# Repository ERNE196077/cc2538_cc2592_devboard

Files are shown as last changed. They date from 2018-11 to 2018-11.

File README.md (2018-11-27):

# cc2538_cc2592_devboard
This board is small enough to fit in a breadboard and let one space for pin connectivity, some features are:
* APA102 2020 onboard.
* FTDI FT232 UART-USB transceiver onboard 
* SN74AHCT125 onboard for 5v TTL (PA5 & PA6)
* RP SMA Female connector for high gain antenna
* Power consumption with LED working and SPI trasmitting each 100 ms = 0.05 A
* Dedicated Flash (PA2) and Reset buttons. 

## Flashing instructions for OpenThread
I'm using the cc2538-bsl.py script from JelmerT to flash the board. All the recognitions goes to him: 
[cc2538-bsl](https://github.com/JelmerT/cc2538-bsl)

Set the bootloader in the board: Press Reset button while holding the Flash button.
Compile the cc2538 example as seen in the [OpenThread.io](https://openthread.io/guides/build) page.

*NOTE* Make sure to modify the dedicated pins in the file /examples/platforms/cc2538/startup-gcc.c to match the above ones.

Convert to binary the resulting image
```
arm-none-eabi-objcopy -O binary output/cc2538/bin/ot-cli-ftd output/cc2538/bin/ot-cli-ftd.bin
```
Flash the image
```
sudo python ./cc2538-bsl/cc2538-bsl.py -p /dev/ttyUSB0 -b 115200 -e -w -v -V  output/cc2538/bin/ot-cli-ftd.bin
```

## KICAD dependencies 
Make sure to update your KICAD and update the libraries. Then you will need to link and match the footprints and schematic components.
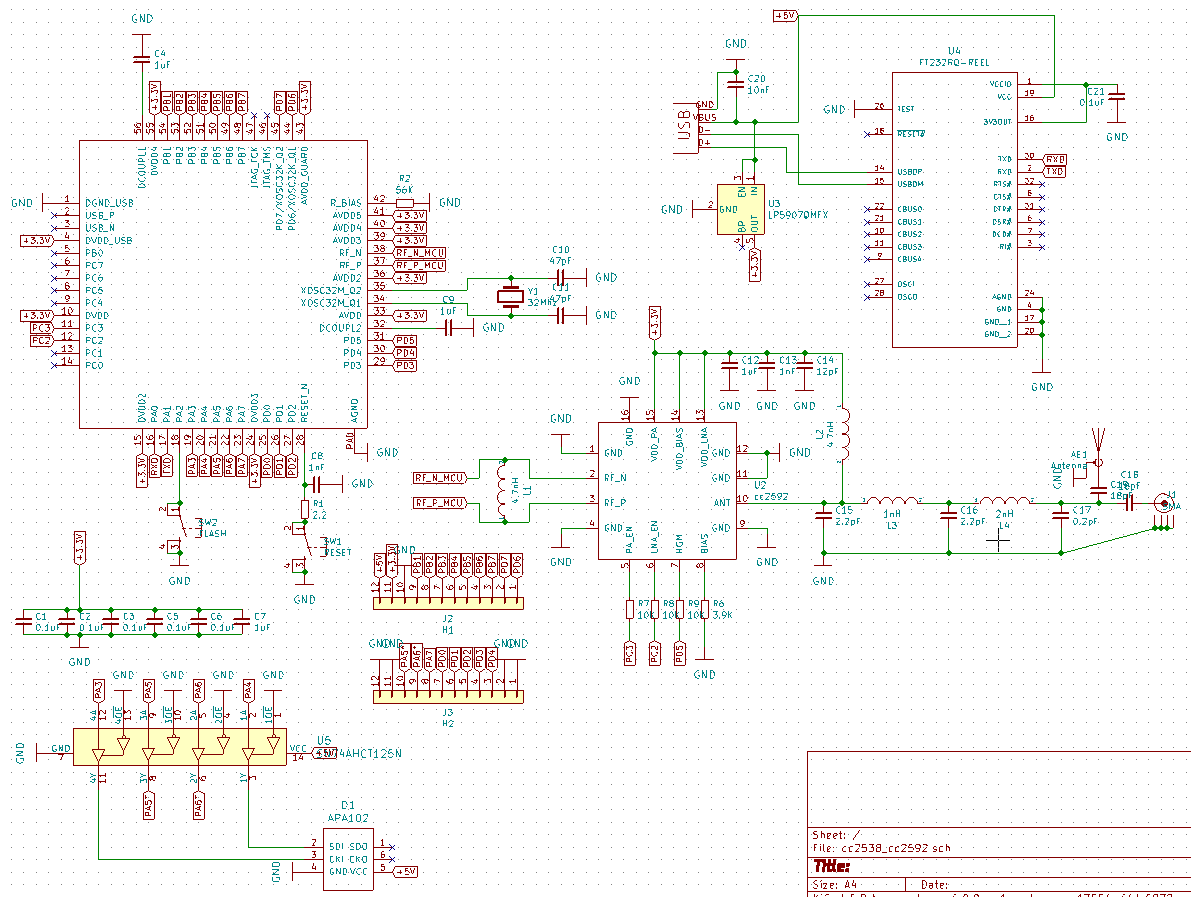
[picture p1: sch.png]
Schematic

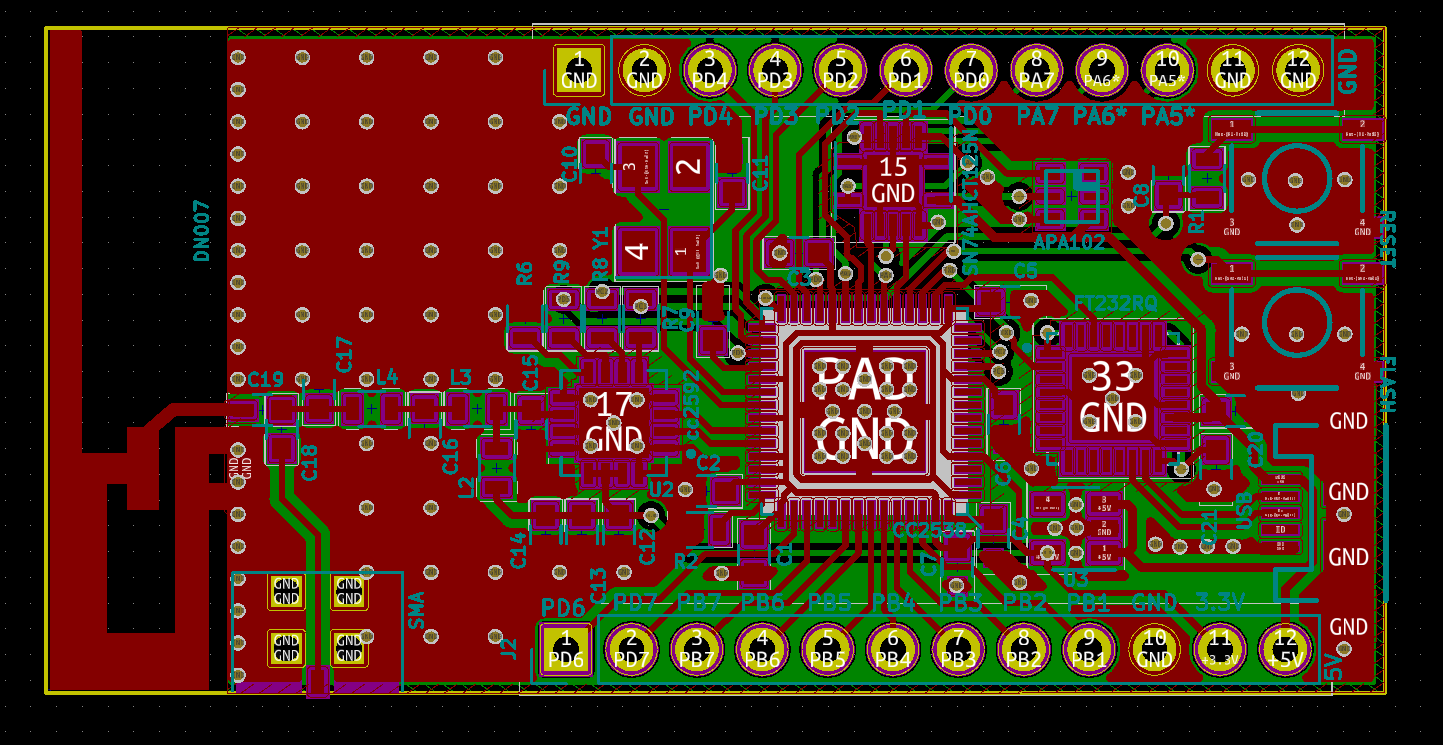
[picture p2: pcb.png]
PCB layout

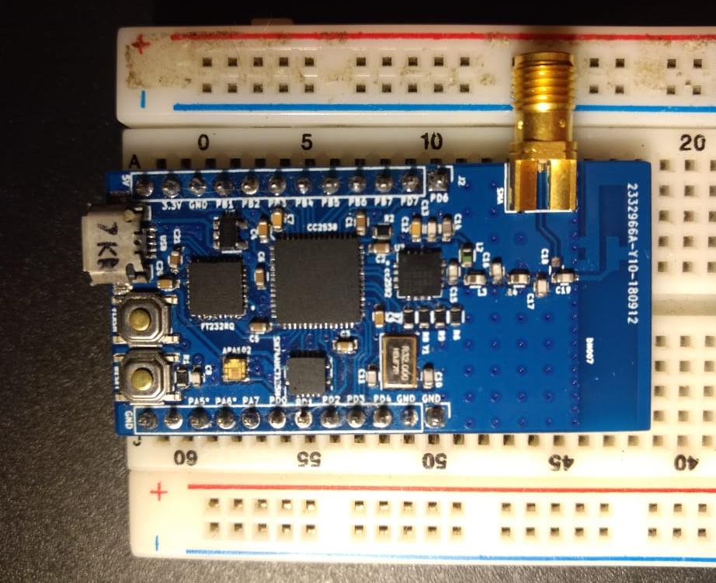
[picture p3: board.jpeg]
Board


## Libraries

Most of the work done with this board has been based in the OpenThread project, but custom libraries are available to fit the capabilities of this board:
[OpenThread](https://github.com/openthread/openthread)
[cc2538_cc2592_libs](https://github.com/ERNE196077/cc2538_cc2592_libs)

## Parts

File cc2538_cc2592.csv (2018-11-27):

Title
Revision
Date
Generated | Sun 10 Jun 2018 07:34:57 PM CDT
Company
Comment 1
Comment 2
Comment 3
Comment 4
Total Parts | 44
Total Unique Parts | 29
Ref | Qty | Value | Footprint | Datasheet | Field4 | Field5 | Field6 | Field7 | Field8
AE1 | 1 | Antenna | Antennas:Texas_SWRA117D_2.4GHz_Right
C1 C2 C3 C5 C6 C21 | 6 | 0.1uF | Capacitors_SMD:C_0603
C4 C7 C9 C12 | 4 | 1uF | Capacitors_SMD:C_0603
C8 C13 | 2 | 1nF | Capacitors_SMD:C_0603
C10 C11 | 2 | 47pF | Capacitors_SMD:C_0603
C14 | 1 | 12pF | Capacitors_SMD:C_0603
C15 C16 | 2 | 2.2pF | Capacitors_SMD:C_0603
C17 | 1 | 0.2pF | Capacitors_SMD:C_0603
C18 C19 | 2 | 18pF | Capacitors_SMD:C_0603
C20 | 1 | 10nF | Capacitors_SMD:C_0603
D1 | 1 | APA102 | gsg-modules:APA102-2020
J1 | 1 | A-1JB | A-1JB:AMPHENOL_A-1JB | Amphenol RF | 0.50 USD | A-1JB | Good | None | Connector | RF | AMC | PCB Jack | Surface Mnt | 50 Ohm | Solder
J2 | 1 | H1 | Pin_Headers:Pin_Header_Straight_1x18_Pitch2.54mm
J3 | 1 | H2 | Pin_Headers:Pin_Header_Straight_1x18_Pitch2.54mm
L1 L2 | 2 | 4.7nH | Inductors_SMD:L_0603
L3 | 1 | 1nH | Inductors_SMD:L_0603
L4 | 1 | 2nH o 1.8nH | Inductors_SMD:L_0603
R1 | 1 | 2.2 | Resistors_SMD:R_0603
R2 | 1 | 56K | Resistors_SMD:R_0603
R6 | 1 | 3.9K | Resistors_SMD:R_0603
R7 R8 R9 | 3 | 10K | Resistors_SMD:R_0603
SW1 | 1 | RESET | cc2538node:TACTILE_SWITCH_SMD
SW2 | 1 | FLASH | cc2538node:TACTILE_SWITCH_SMD
U1 | 1 | CC2538 | cc2538node:QFN56
U2 | 1 | cc2592 | QFN65P400X400X100-17N:QFN65P400X400X100-17N
U3 | 1 | LP5907QMFX | TO_SOT_Packages_SMD:SOT-23-5 | http://ww1.microchip.com/downloads/en/devicedoc/mic5219.pdf
U4 | 1 | FT232RQ-REEL | FT232RQ-REEL:QFN50P500X500X100-33N | Unavailable | None | FT232RQ | USB-to-UART 1-CH 256Byte FIFO 5V 32-Pin QFN EP | FTDI | 3.77 USD
USB1 | 1 | USBSMD | cc2538node:USB-MICROB
Y1 | 1 | 32Mhz | Crystals:Crystal_SMD_5032-4pin_5.0x3.2mm
BOM made with KICAD_BOM_WIZARD (https://github.com/HashDefineElectronics/KiCad_BOM_Wizard.git)
Generated Sun 10 Jun 2018 07:34:57 PM CDT

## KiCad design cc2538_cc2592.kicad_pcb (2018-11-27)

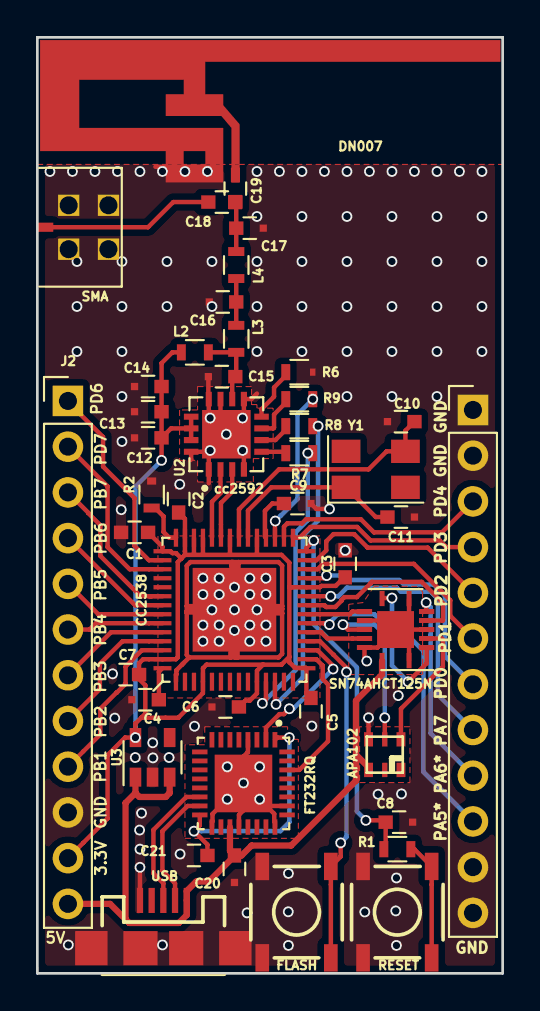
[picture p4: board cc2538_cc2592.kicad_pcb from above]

Board: 2 copper layers, 25.9 x 52.0 mm, 44 parts (0 on the bottom side), 53 nets.

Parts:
APA102: APA102; APA102-2020
C1, C2, C3, C5, C6, C21: 0.1uF; C_0603
C4, C7, C9, C12: 1uF; C_0603
C8, C13: 1nF; C_0603
C10, C11: 47pF; C_0603
C14: 12pF; C_0603
C15, C16: 2.2pF; C_0603
C17: 0.2pF; C_0603
C18, C19: 18pF; C_0603
C20: 10nF; C_0603
CC2538: CC2538; QFN56
DN007: Antenna; Texas_DN007
J2: H1; Pin_Header_Straight_1x12_Pitch2.54mm
J3: H2; Pin_Header_Straight_1x12_Pitch2.54mm
L2: 4.7nH; L_0603
L3: 1nH; L_0603
L4: 2nH; L_0603
R1: 2.2; R_0603
R2: 56K; R_0603
R6: 3.9K; R_0603
R7, R8, R9: 10K; R_0603
SMA: SMA; MOLEX_SMA_F_3460
SN74AHCT125N: SN74AHCT125N; Texas_S-PVQFN-N14
SW1: RESET; TACTILE_SWITCH_SMD
SW2: FLASH; TACTILE_SWITCH_SMD
U2: cc2592; QFN65P400X400X100-17N
U3: LP5907QMFX; SOT-23-5
U4: FT232RQ; QFN50P500X500X100-33N
USB1: USB; USB-MICROB
Y1: 32Mhz; Crystal_SMD_5032-4pin_5.0x3.2mm

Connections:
+3.3V: C1.1, C2.1, C3.1, C5.1, C6.1, C7.1, C12.1, C13.1, C14.1, CC2538.4, CC2538.10, CC2538.15, CC2538.24, CC2538.33, CC2538.36, CC2538.39, CC2538.40, CC2538.41, CC2538.43, CC2538.55, J2.11, L2.1, U2.13, U2.14, U2.15, U3.5
+5V: APA102.5, C20.2, J2.12, SN74AHCT125N.14, U3.1, U3.3, U4.19, USB1.VBUS
GND: APA102.4, C1.2, C2.2, C3.2, C4.1, C5.2, C6.2, C7.2, C8.1, C9.1, C10.1, C11.1, C12.2, C13.2, C14.2, C15.2, C16.2, C17.2, C20.1, C21.2, CC2538.1, CC2538.PAD, DN007.GND, J2.10, J3.1, J3.2, J3.11, J3.12, R2.1, R6.2, SMA.GND, SN74AHCT125N.1, SN74AHCT125N.4, SN74AHCT125N.7, SN74AHCT125N.10, SN74AHCT125N.13, SN74AHCT125N.15, SW1.3, SW1.4, SW2.3, SW2.4, U2.1, U2.4, U2.9, U2.11, U2.12, U2.16, U2.17, U3.2, U4.4, U4.17, U4.20, U4.24, U4.26, U4.33, USB1.GND
unnamed: C19.2, DN007.1
unnamed: C4.2, CC2538.56
unnamed: C8.2, CC2538.28, R1.1
unnamed: C9.2, CC2538.32
unnamed: C10.2, CC2538.35, Y1.3
unnamed: C11.2, CC2538.34, Y1.1
unnamed: C15.1, L2.2, L3.1, U2.10
unnamed: C16.1, L3.2, L4.1
unnamed: C17.1, C18.2, C19.1, L4.2
unnamed: C18.1, SMA.1
unnamed: C21.1, U4.1, U4.16
unnamed: APA102.2, SN74AHCT125N.3
unnamed: APA102.3, SN74AHCT125N.11
unnamed: R1.2, SW1.1, SW1.2
unnamed: CC2538.42, R2.2
unnamed: R6.1, U2.8
unnamed: R7.1, U2.5
unnamed: R8.1, U2.6
unnamed: R9.1, U2.7
unnamed: CC2538.18, SW2.1, SW2.2
unnamed: U4.14, USB1.D+
unnamed: U4.15, USB1.D-
PA3: CC2538.19, SN74AHCT125N.12
PA4: CC2538.20, SN74AHCT125N.2
PA5: CC2538.21, SN74AHCT125N.9
PA5*: J3.10, SN74AHCT125N.8
PA6: CC2538.22, SN74AHCT125N.5
PA6*: J3.9, SN74AHCT125N.6
PA7: CC2538.23, J3.8
PB1: CC2538.54, J2.9
PB2: CC2538.53, J2.8
PB3: CC2538.52, J2.7
PB4: CC2538.51, J2.6
PB5: CC2538.50, J2.5
PB6: CC2538.49, J2.4
PB7: CC2538.48, J2.3
PC2: CC2538.12, R8.2
PC3: CC2538.11, R7.2
PD0: CC2538.25, J3.7
PD1: CC2538.26, J3.6
PD2: CC2538.27, J3.5
PD3: CC2538.29, J3.4
PD4: CC2538.30, J3.3
PD5: CC2538.31, R9.2
PD6: CC2538.44, J2.1
PD7: CC2538.45, J2.2
RF_N_MCU: CC2538.38, U2.2
RF_P_MCU: CC2538.37, U2.3
RXD: CC2538.16, U4.30
TXD: CC2538.17, U4.2
